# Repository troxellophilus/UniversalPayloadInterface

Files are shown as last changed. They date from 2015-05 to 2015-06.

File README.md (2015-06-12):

# UniversalPayloadInterface
Universal UAV Payload Interface Senior Project

Open Source Code & Hardware

Cal Poly SLO

* Nolan Reker
* Drew Troxell
* David Troy

More documentation coming soon!

### Getting Started

#### Requirements
* UAV utilizing the Mavlink protocol
* Onboard proxy device for running MAVProxy
* Atmega328p on payload interface board (see pcb directory for hardware details)

#### Loading the source
* Compile and upload the payload_atmega328p ino project to the atmega328p payload interface board using your favorite AVR compiler/loader.
* Connect the interface board to the onboard device via UART.
* Run MAVProxy on the onboard device w/ the master device set to the autopilot and the output device set to the UART connection to the interface board.
* The onboard LED will light up after successfully receiving 10 heartbeat packets from the autopilot.

#### Modifying the source
This code is meant to provide a simple example and framework for communicating between a payload and an autopilot via Mavlink. Reference the mavlink library for functions to decode or send more messages via mavlink.

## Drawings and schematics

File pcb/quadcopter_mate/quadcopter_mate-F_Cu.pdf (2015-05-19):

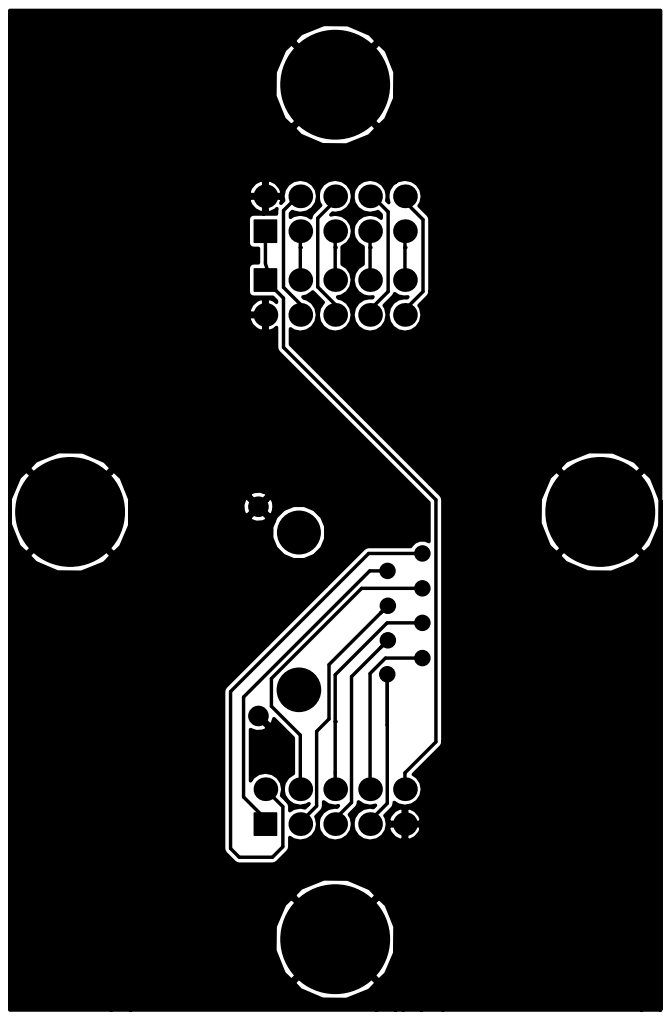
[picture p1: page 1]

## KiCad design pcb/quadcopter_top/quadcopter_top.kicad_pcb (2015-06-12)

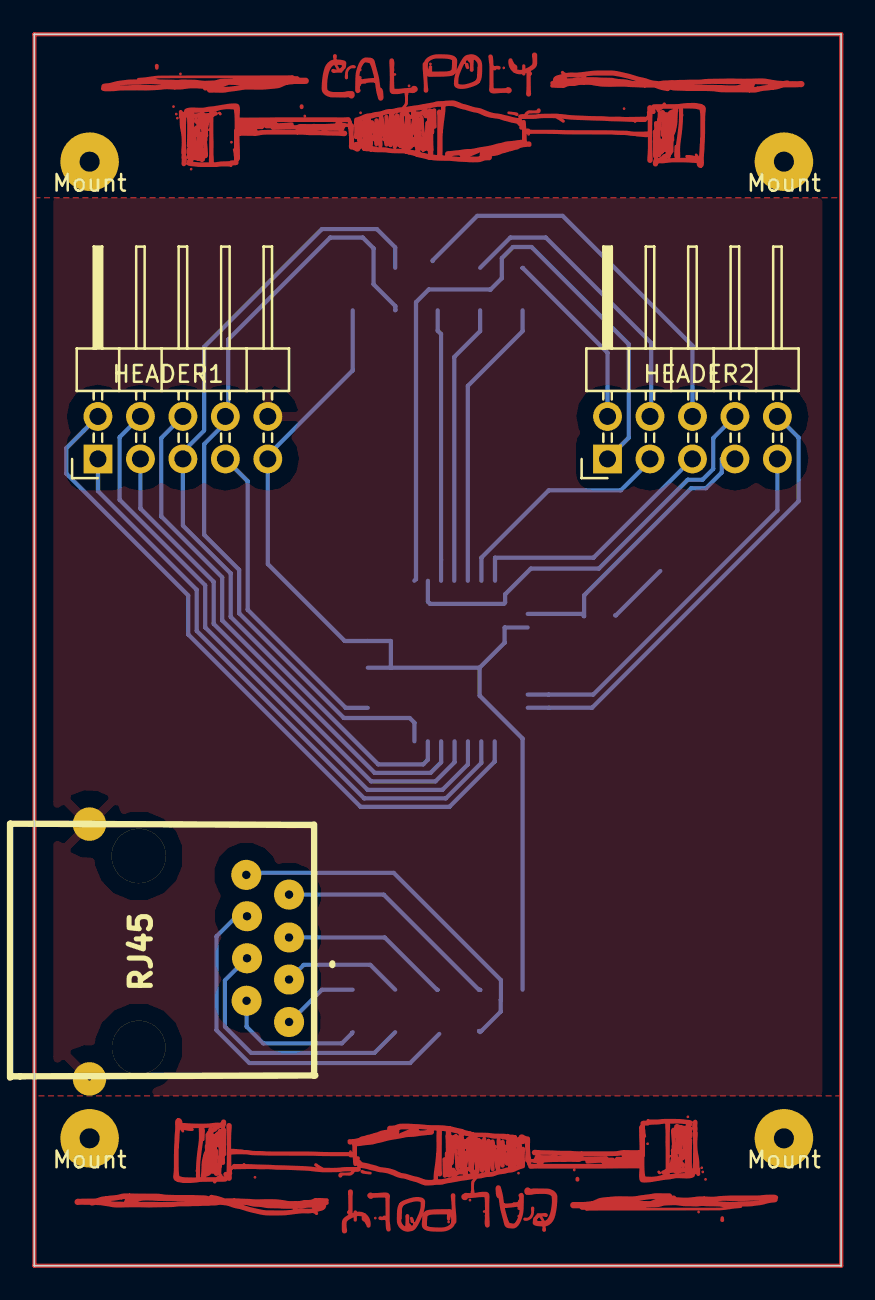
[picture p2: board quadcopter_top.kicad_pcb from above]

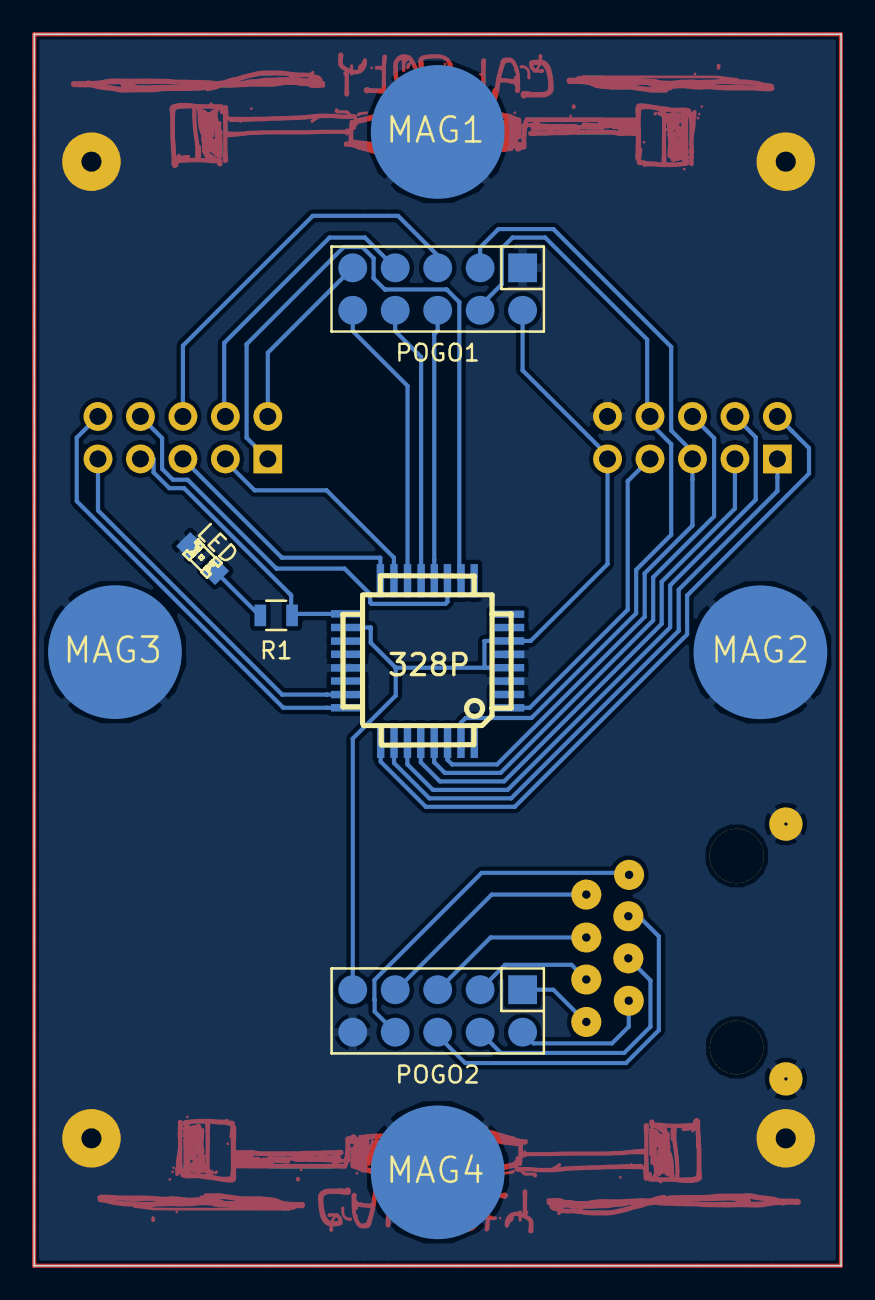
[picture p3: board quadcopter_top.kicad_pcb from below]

Board: 2 copper layers, 48.3 x 73.7 mm, 16 parts (9 on the bottom side), 32 nets.

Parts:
328P: ATMEGA328P-A; TQFP32_08
HEADER1, HEADER2: CONN_02X05; Pin_Header_Angled_2x05
J1: RJ45
LED: LED; LED-0805
MAG1, MAG2, MAG3, MAG4: CONN_01X01; 8mmMagnet
Mount: Mount; SolderWirePad_single_1-2mmDrill
Mount#2, Mount#3, Mount#4: Mount; SolderWirePad_single_1-2mmDrill
POGO1, POGO2: CONN_02X05; Pin_Header_Straight_2x05_SMD
R1: R; R_0805

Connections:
+5V: 328P.4, 328P.6, 328P.18, HEADER1.9, POGO1.2, POGO2.9
GND: 328P.3, 328P.5, 328P.21, HEADER1.10, J1.9, LED.1, MAG1.1, MAG2.1, MAG3.1, MAG4.1, POGO1.1, POGO2.10
unnamed: LED.2, R1.2
unnamed: 328P.26, HEADER1.1
unnamed: 328P.25, HEADER1.2
unnamed: 328P.28, HEADER1.3
unnamed: 328P.27, HEADER1.4
unnamed: 328P.30, HEADER1.5, POGO1.3
unnamed: 328P.29, HEADER1.6
unnamed: 328P.1, HEADER1.7
unnamed: 328P.31, HEADER1.8, POGO1.4
unnamed: 328P.10, HEADER2.1
unnamed: HEADER2.2, POGO1.9
unnamed: 328P.15, HEADER2.3
unnamed: HEADER2.4, POGO1.7
unnamed: 328P.16, HEADER2.5
unnamed: HEADER2.6, POGO1.5
unnamed: 328P.17, HEADER2.7, R1.1
unnamed: 328P.11, HEADER2.8
unnamed: 328P.23, HEADER2.9
unnamed: 328P.24, HEADER2.10
unnamed: 328P.12, POGO1.6
unnamed: 328P.13, POGO1.8
unnamed: 328P.14, POGO1.10
unnamed: J1.1, POGO2.8
unnamed: J1.2, POGO2.7
unnamed: J1.3, POGO2.6
unnamed: J1.4, POGO2.5
unnamed: J1.5, POGO2.4
unnamed: J1.6, POGO2.3
unnamed: J1.7, POGO2.2
unnamed: J1.8, POGO2.1

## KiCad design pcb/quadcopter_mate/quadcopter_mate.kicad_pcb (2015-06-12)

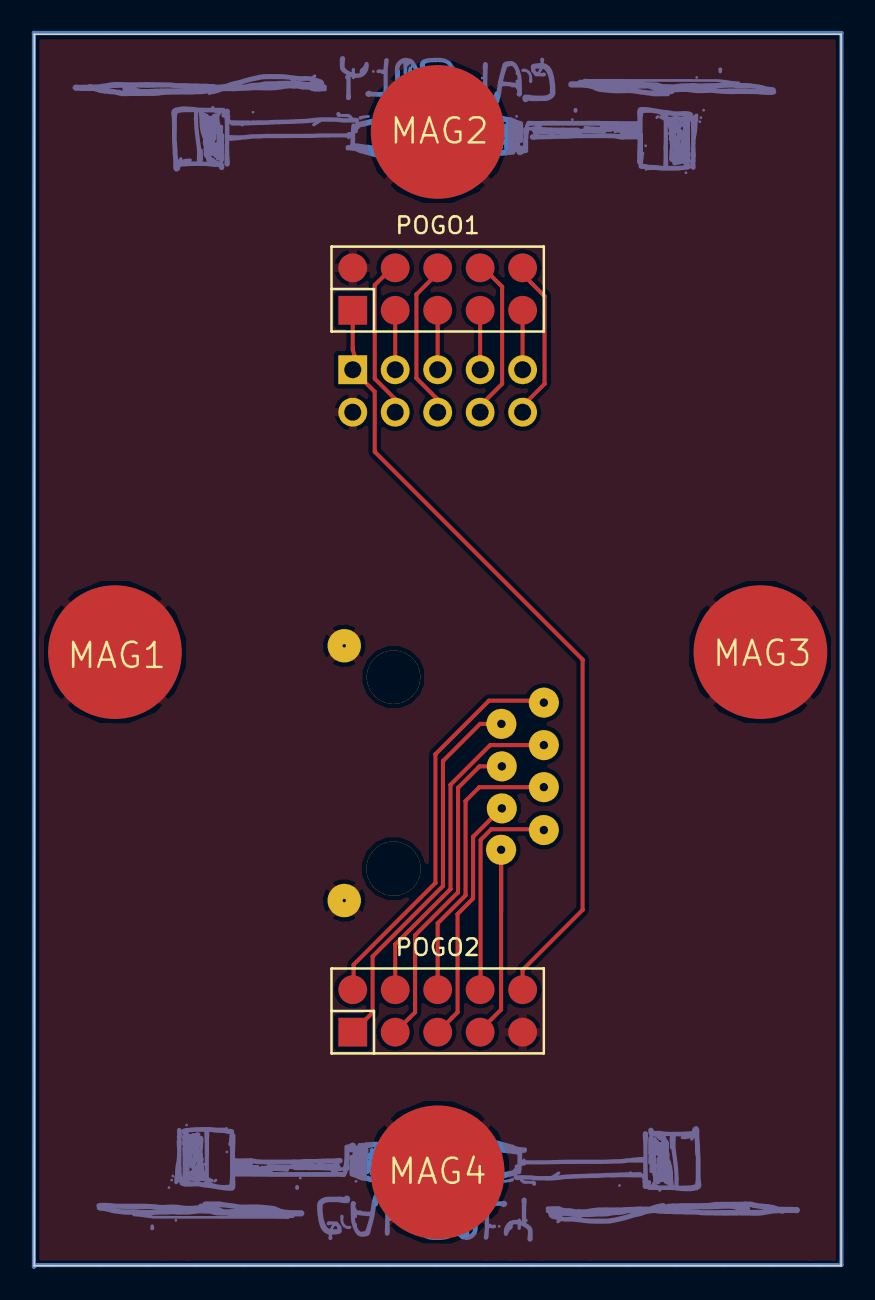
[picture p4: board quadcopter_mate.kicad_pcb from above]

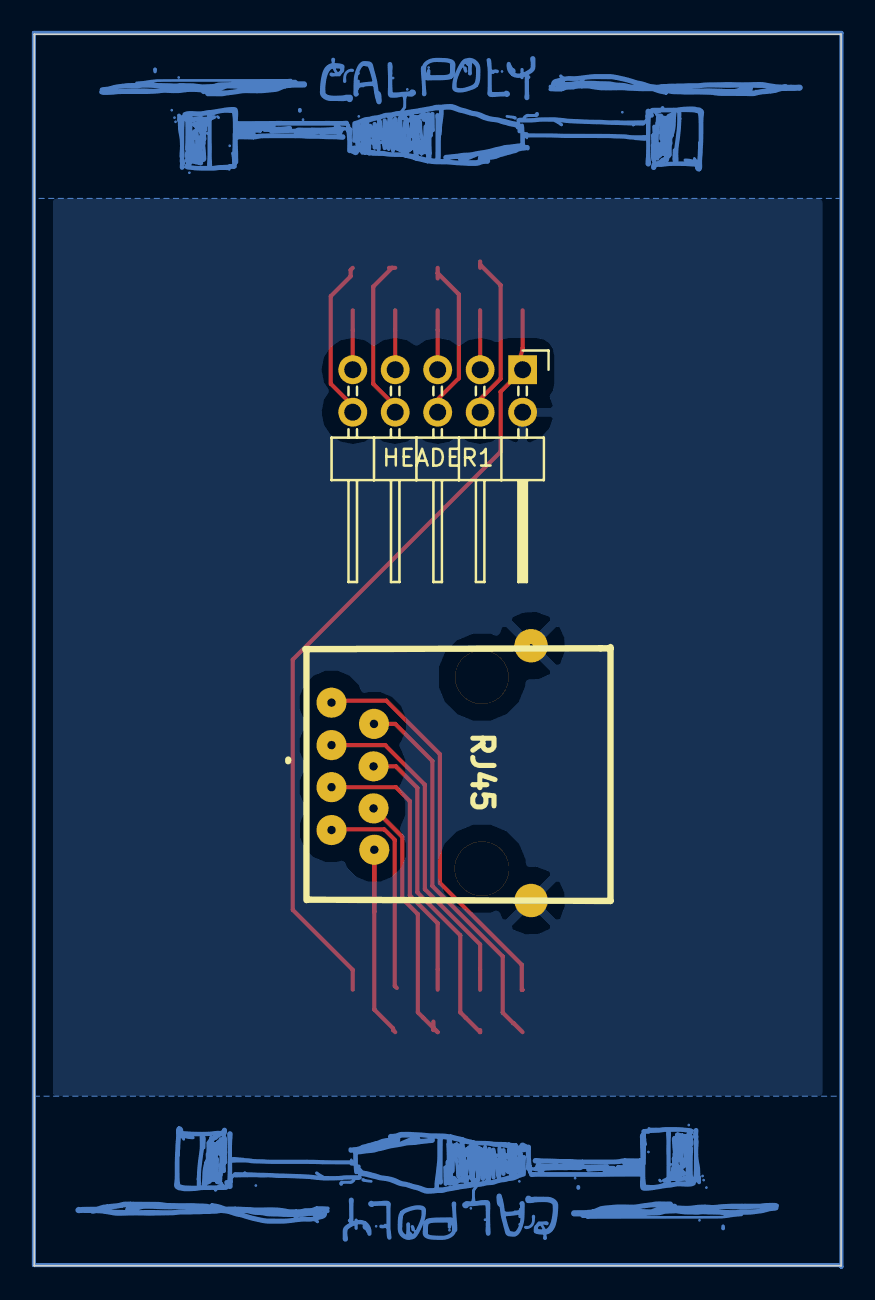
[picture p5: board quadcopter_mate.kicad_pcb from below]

Board: 2 copper layers, 48.3 x 73.7 mm, 8 parts (2 on the bottom side), 18 nets.

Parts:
HEADER1: CONN_02X05; Pin_Header_Angled_2x05
J1: RJ45
MAG1, MAG2, MAG3, MAG4: CONN_01X01; 8mmMagnet
POGO1, POGO2: CONN_02X05; Pin_Header_Straight_2x05_SMD

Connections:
+5V: HEADER1.1, POGO1.1, POGO2.10
GND: HEADER1.2, J1.9, MAG1.1, MAG2.1, MAG3.1, MAG4.1, POGO1.2, POGO2.9
unnamed: HEADER1.3, POGO1.3
unnamed: HEADER1.4, POGO1.4
unnamed: HEADER1.5, POGO1.5
unnamed: HEADER1.6, POGO1.6
unnamed: HEADER1.7, POGO1.7
unnamed: HEADER1.8, POGO1.8
unnamed: HEADER1.9, POGO1.9
unnamed: HEADER1.10, POGO1.10
unnamed: J1.1, POGO2.7
unnamed: J1.2, POGO2.8
unnamed: J1.3, POGO2.5
unnamed: J1.4, POGO2.6
unnamed: J1.5, POGO2.3
unnamed: J1.6, POGO2.4
unnamed: J1.7, POGO2.1
unnamed: J1.8, POGO2.2

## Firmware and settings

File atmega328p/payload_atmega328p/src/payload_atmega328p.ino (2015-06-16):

/*
 * Universal Payload Interface
 * Atmega328p MAVLink Code
 */

/* Make sure this is included before Arduino's HardwareSerial */
#include <FastSerial.h>

/* Make sure this is defined before including mavlink.h */
#define MAVLINK_COMM_NUM_BUFFERS 1
#include <mavlink.h>

#define PL_SYS_ID  101 // system id of the payload interface
#define PL_COMP_ID 101 // Component id of payload interface

#define NUM_WP 5 // the number of waypoints we will send to the mav

#define PL_STATE_DISCONNECTED       0
#define PL_STATE_CONNECTED          1
#define PL_STATE_SEND_WAYPOINTS     2
#define PL_STATE_FLASH_LED          3

FastSerialPort0(Serial); // Required for FastSerial

// System Status Variables
uint8_t  mavlink_connected = 0;
uint8_t  pl_state = PL_STATE_DISCONNECTED;
uint16_t hb_count = 0;
uint32_t led_pin = 13;

// Payload identifiers
uint8_t  pl_system_id = PL_SYS_ID;
uint8_t  pl_component_id = PL_COMP_ID;

// APM identifiers
uint8_t  mav_system_id = 0;
uint8_t  mav_component_id = 0;

// Waypoint Variables
uint8_t  wp_timeout = 0;
uint8_t  wp_clear_sent = 0;
uint8_t  wp_count_sent = 0;
uint8_t  wp_request_seq = 0;
mavlink_mission_item_t pl_waypoints[NUM_WP];

// *************************
// MAVLINK MESSAGE VARIABLES

// Heartbeat (msg id 1)
uint8_t  mav_type = 0;
uint8_t  mav_autopilot = 0;
uint8_t  mav_base_mode = 0;
uint8_t  mav_system_status = 0;

// Mission Current (msg id 42)
uint16_t mav_seq = 0;

// *************************
// MESSAGE SEND HELPERS

void send_message(mavlink_message_t* msg) {
	uint8_t buf[MAVLINK_MAX_PACKET_LEN];

	uint16_t len = mavlink_msg_to_send_buffer(buf, msg);

	for(uint16_t i = 0; i < len; i++) {
		Serial.write(buf[i]);
	}
}

void send_heartbeat() {
	// Define the system type (see mavlink_types.h for list of possible types) 
	int system_type = MAV_TYPE_GCS;
	int autopilot_type = MAV_AUTOPILOT_INVALID;
	int base_mode = MAV_MODE_STABILIZE_ARMED;
	int sys_status = MAV_STATE_ACTIVE;
	
	// Initialize the required buffers 
	mavlink_message_t msg; 
	
	// Setup the heartbeat message
	mavlink_msg_heartbeat_pack(pl_system_id, pl_component_id, &msg, system_type, autopilot_type, base_mode, 0, sys_status);

	send_message(&msg);
}

void send_set_waypoint(uint16_t wp) {
	mavlink_message_t msg;
	mavlink_mission_set_current_t set_point;

	set_point.seq = wp;
	set_point.target_system = mav_system_id;
	set_point.target_component = mav_component_id;

	mavlink_msg_mission_set_current_encode(pl_system_id, pl_component_id, &msg, &set_point);

	send_message(&msg);
}

void send_waypoint_count(uint16_t c) {
	mavlink_message_t msg;
	mavlink_mission_count_t wp_count;

	wp_count.count = c;
	wp_count.target_system = mav_system_id;
	wp_count.target_component = mav_component_id;

	mavlink_msg_mission_count_encode(pl_system_id, pl_component_id, &msg, &wp_count);

	send_message(&msg);
}

void send_waypoint(float lat, float lon, float alt, uint16_t seq, uint16_t com, uint8_t cur) {
	mavlink_message_t msg;
	mavlink_mission_item_t waypoint;

	waypoint.param1 = 0;
	waypoint.param2 = 0;
	waypoint.param3 = 0;
	waypoint.param4 = 0;
	waypoint.x = lat;
	waypoint.y = lon;
	waypoint.z = alt;
	waypoint.seq = seq;
	waypoint.command = com;
	waypoint.target_system = mav_system_id;
	waypoint.target_component = mav_component_id;
	waypoint.frame = MAV_FRAME_BODY_NED;
	waypoint.current = cur;
	waypoint.autocontinue = 1;

	mavlink_msg_mission_item_encode(pl_system_id, pl_component_id, &msg, &waypoint);

	send_message(&msg);
}

void send_waypoint(mavlink_mission_item_t *wp) {
	mavlink_message_t msg;

	mavlink_msg_mission_item_encode(pl_system_id, pl_component_id, &msg, wp);

	send_message(&msg);
}

void send_clear_waypoints() {
	mavlink_message_t msg;
	mavlink_mission_clear_all_t wp_clear;

	wp_clear.target_system = mav_system_id;
	wp_clear.target_component = mav_component_id;

	mavlink_msg_mission_clear_all_encode(pl_system_id, pl_component_id, &msg, &wp_clear);

	send_message(&msg);
}

void send_status_text(char * txt, MAV_SEVERITY severity) {
	mavlink_message_t msg;
	mavlink_statustext_t status_text;

	status_text.severity = severity;
	memcpy(status_text.text, txt, 50);

	mavlink_msg_statustext_encode(mav_system_id, mav_component_id, &msg, &status_text);

	send_message(&msg);
}

// ************************
// PAYLOAD UPDATE FUNCTIONS

void pl_update() {
	static uint16_t frames = 0;

	// Run payload state machine
	switch (pl_state) {
		case PL_STATE_DISCONNECTED:
			digitalWrite(led_pin, LOW);

			// Received 10 heartbeats, connection confirmed
			if (hb_count >= 10) {
				pl_state = PL_STATE_CONNECTED;

				// update the target ids in the waypoint list
				int i;
				for (i = 0; i < NUM_WP; i++) {
					pl_waypoints[i].target_system = mav_system_id;
					pl_waypoints[i].target_component = mav_component_id;
				}
			}

			// send heartbeats from the payload
			delay(10);
			send_heartbeat();

			// while a connection hasn't been established, do nothing
			break;
		case PL_STATE_CONNECTED:
			digitalWrite(led_pin, HIGH);

			if (wp_count_sent == 0) {
				// allow the autopilot to warm up
				delay(5000);

				// clear out any waypoints already on the autopilot
				//send_clear_waypoints();
				//wp_clear_sent = 1;

				pl_state = PL_STATE_SEND_WAYPOINTS;
			}

			// send heartbeats from the payload
			delay(10);
			send_heartbeat();

			break;
		case PL_STATE_FLASH_LED:
			int i;

			// flash the LED 5 times in 1 second to visually acknowledge something
			for (i = 0; i < 5; i++) {
				if (digitalRead(led_pin) == HIGH)
					digitalWrite(led_pin, LOW);
				else
					digitalWrite(led_pin, HIGH);
				delay(200);
			}

			pl_state = PL_STATE_CONNECTED;
			break;
		case PL_STATE_SEND_WAYPOINTS:
			static unsigned long last_time = millis();

			if (wp_count_sent && millis() - last_time >= 2000) {
				last_time = millis();
				wp_timeout++;

				// handle timeouts depending on current request seq
				if (wp_timeout >= 5) {
					wp_count_sent = 0;
					wp_timeout = 0;
				}
				else {
					send_waypoint(&pl_waypoints[wp_request_seq]);
				}
			}
			
			if (wp_count_sent == 0) {
				send_waypoint_count(NUM_WP);
				wp_count_sent++;
			}

			// recv handlers will handle sending waypoints when requested
			break;
	}

	frames++;
}

// ************************
// MAIN SETUP AND LOOP

void init_waypoint(float lat, float lon, float alt, uint16_t seq, uint16_t com, uint8_t cur,
							mavlink_mission_item_t *waypoint) {
	waypoint->param1 = 0;
	waypoint->param2 = 0;
	waypoint->param3 = 0;
	waypoint->param4 = 0;
	waypoint->x = lat;
	waypoint->y = lon;
	waypoint->z = alt;
	waypoint->seq = seq;
	waypoint->command = com;
	waypoint->target_system = mav_system_id;
	waypoint->target_component = mav_component_id;
	waypoint->frame = MAV_FRAME_BODY_NED;
	waypoint->current = cur;
	waypoint->autocontinue = 1;
}

void setup() {
	pinMode(led_pin, OUTPUT);
	Serial.begin(57600);

	// Initialize the waypoint list
	//   Modify the init_waypoints in the switch statement and NUM_WP to change waypoints
	int i = 0;
	mavlink_mission_item_t waypoint;
	while (i < NUM_WP) {
		switch (i) {
			case 0:
				// "Home" waypoint, gets overridden by APM
				init_waypoint(0, 0, 0, i, MAV_CMD_NAV_WAYPOINT, 0, &waypoint);
				break;
			case 1:
				// Takeoff, only cares about altitude param
				init_waypoint(0, 0, 1.0, i, MAV_CMD_NAV_TAKEOFF, 0, &waypoint);
				break;
			case 2:
				// Spin around a bit
				init_waypoint(0, 0, 0, i, MAV_CMD_CONDITION_YAW, 0, &waypoint);
				waypoint.param1 = 180.0; // degrees to spin
				waypoint.param4 = 1.0; // around current rotation
			case 3:
				// Navigate according to body frame of reference
				init_waypoint(0.0, 0.0, 1.0, i, MAV_CMD_NAV_WAYPOINT, 0, &waypoint);
				break;
			case 4:
				// Return to launch, self explanatory
				init_waypoint(0, 0, 0, i, MAV_CMD_NAV_RETURN_TO_LAUNCH, 0, &waypoint);
				break;
		}
		pl_waypoints[i] = waypoint;
		i++;
	}
}

void loop() { 
	// Carry out payload state machine
	pl_update();
	
	// Receive messages and handle them
	comm_receive();
}

// ************************
// MESSAGE RECEIVE HELPERS

void comm_receive() {
	static unsigned long last_time = millis();
	static uint8_t timeout = 0;
	int i = 0;
	int frames = 0;
	mavlink_message_t recv_msg; 
	mavlink_status_t recv_status;

	// block for 1 second on serial read
	while (Serial.available() == 0 && pl_state != PL_STATE_DISCONNECTED) {
		if (millis() - last_time >= 1000) {
			last_time = millis();
			timeout++; // block on serial read
		}

		// we haven't heard from the autopilot in 10 seconds
		if (timeout >= 10) {
			pl_state = PL_STATE_DISCONNECTED;
			mavlink_connected = 0;
			hb_count = 0;
			wp_clear_sent = 0;
			wp_count_sent = 0;
			wp_request_seq = 0;
		}
	}
	
	// receive data over serial 
	while (Serial.available() > 0) { 
		uint8_t c = Serial.read();

		//try to get a new message 
		if(mavlink_parse_char(0, c, &recv_msg, &recv_status)) { 
			timeout = 0; // reset timeout
			frames++;
			
			// Update system and component id
			mav_system_id = recv_msg.sysid;
			mav_component_id = recv_msg.compid;

			// Handle message
 			switch(recv_msg.msgid) {
			        case MAVLINK_MSG_ID_HEARTBEAT:
					handle_heartbeat(&recv_msg);
			        	break;
				case MAVLINK_MSG_ID_MISSION_CURRENT:
					handle_mission_current(&recv_msg);
					break;
				case MAVLINK_MSG_ID_MISSION_REQUEST:
					handle_mission_request(&recv_msg);
					break;
				case MAVLINK_MSG_ID_MISSION_ACK:
					handle_mission_ack(&recv_msg);
					break;
				default:
				break;
			}
		} 
		if (i > 64 || frames > 10) {
			break;
		}
		delayMicroseconds(200);
		i++;
	}
}

void handle_heartbeat(mavlink_message_t *msg) {
	hb_count++;
	mav_type = mavlink_msg_heartbeat_get_type(msg);
	mav_autopilot = mavlink_msg_heartbeat_get_autopilot(msg);
	mav_base_mode = mavlink_msg_heartbeat_get_base_mode(msg);
	mav_system_status = mavlink_msg_heartbeat_get_system_status(msg);
}

void handle_mission_current(mavlink_message_t *msg) {
	mav_seq = mavlink_msg_mission_current_get_seq(msg);
	//pl_state = PL_STATE_FLASH_LED;
}

void handle_mission_request(mavlink_message_t *msg) {
	wp_timeout = 0;
	wp_request_seq = mavlink_msg_mission_request_get_seq(msg);
	send_waypoint(&pl_waypoints[wp_request_seq]);
}

void handle_mission_ack(mavlink_message_t *msg) {
	wp_request_seq = 0;
	pl_state = PL_STATE_FLASH_LED;
}

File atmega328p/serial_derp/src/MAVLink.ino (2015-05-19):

/*
	 Mav2DupEx Version 0.1
	 2014, by DevFor8.com, info@devfor8.com
	 
	 part of code is based on ArduCAM OSD
*/

#include "../GCS_MAVLink/include/mavlink/v1.0/mavlink_types.h"
#include "../GCS_MAVLink/include/mavlink/v1.0/ardupilotmega/mavlink.h"

#include "Vars.h"

// true when we have received at least 1 MAVLink packet
static bool mavlink_active;
static uint8_t crlf_count = 0;

static int packet_drops = 0;
static int parse_error = 0;

boolean getBit(byte Reg, byte whichBit) {
    boolean State;
    State = Reg & (1 << whichBit);
    return State;
}  

/*
void request_mavlink_rates()
{
    const int  maxStreams = 6;
    const uint8_t MAVStreams[maxStreams] = {MAV_DATA_STREAM_RAW_SENSORS,
        MAV_DATA_STREAM_EXTENDED_STATUS,
        MAV_DATA_STREAM_RC_CHANNELS,
        MAV_DATA_STREAM_POSITION,
        MAV_DATA_STREAM_EXTRA1, 
        MAV_DATA_STREAM_EXTRA2};
    const uint16_t MAVRates[maxStreams] = {0x02, 0x02, 0x05, 0x02, 0x05, 0x02};
    for (int i=0; i < maxStreams; i++) {
        mavlink_msg_request_data_stream_send(MAVLINK_COMM_0,
            apm_mav_system, apm_mav_component,
            MAVStreams[i], MAVRates[i], 1);
    }
}
*/

void read_mavlink(int maxframes){
    mavlink_message_t msg; 
    mavlink_status_t status;
    int current_frames = 0;

    //grabing data 
    while(Serial.available() > 0) { 
        uint8_t c = Serial.read();
        //Serial.print(c);        Serial.print(" ");

        //trying to grab msg  
        if(mavlink_parse_char(MAVLINK_COMM_0, c, &msg, &status)) {
            mavlink_active = 1;
            current_frames++; //this is frame
            //handle msg
            switch(msg.msgid) {
            case MAVLINK_MSG_ID_HEARTBEAT:
                {
                  Serial.println("beat");
                    mavbeat = 1;
                    apm_mav_system    = msg.sysid;
                    apm_mav_component = msg.compid;
                    apm_mav_type      = mavlink_msg_heartbeat_get_type(&msg);            
                 //   osd_mode = mavlink_msg_heartbeat_get_custom_mode(&msg);
                    osd_mode = (uint8_t)mavlink_msg_heartbeat_get_custom_mode(&msg);
                    //Mode (arducoper armed/disarmed)
                    base_mode = mavlink_msg_heartbeat_get_base_mode(&msg);
                    if(getBit(base_mode,7)) motor_armed = 1;
                    else motor_armed = 0;

                    lastMAVBeat = millis();
                    if(waitingMAVBeats == 1){
                        enable_mav_request = 1;
                    }
                }
                break;
            case MAVLINK_MSG_ID_STATUSTEXT:
                {
                  Serial.println("stext");
                  char text[MAVLINK_MSG_ID_STATUSTEXT_LEN] ;
                  mavlink_msg_statustext_get_text(&msg,&text[0]);
                  strncpy((char*)LastMessage,text,LCDMaxPos);
                  break;
                }
            case MAVLINK_MSG_ID_SYS_STATUS:
                {
                  Serial.println("status");
                    osd_vbat_A = (mavlink_msg_sys_status_get_voltage_battery(&msg) / 1000.0f); //Battery voltage, in millivolts (1 = 1 millivolt)
                    osd_curr_A = (mavlink_msg_sys_status_get_current_battery(&msg) / 100.0f); //Battery current, in 10*milliamperes (1 = 10 milliampere)         10
                    osd_battery_remaining_A = mavlink_msg_sys_status_get_battery_remaining(&msg); //Remaining battery energy: (0%: 0, 100%: 100)
                }
                break;

            case MAVLINK_MSG_ID_GPS_RAW_INT:
                {
                  Serial.println("gps:");
                    osd_lat = mavlink_msg_gps_raw_int_get_lat(&msg) / 10000000.0f;
                    osd_lon = mavlink_msg_gps_raw_int_get_lon(&msg) / 10000000.0f;
                    osd_fix_type = mavlink_msg_gps_raw_int_get_fix_type(&msg);
                    osd_satellites_visible = mavlink_msg_gps_raw_int_get_satellites_visible(&msg);
                  //serial.println(osd_fix_type);

                }
                break; 
            case MAVLINK_MSG_ID_VFR_HUD:
                {
                  Serial.println("hud:");
                    //osd_airspeed = mavlink_msg_vfr_hud_get_airspeed(&msg);
                    //osd_groundspeed = mavlink_msg_vfr_hud_get_groundspeed(&msg);
                    osd_heading = mavlink_msg_vfr_hud_get_heading(&msg); // 0..360 deg, 0=north
                  //Serial.println(osd_heading);  
                    //osd_throttle = mavlink_msg_vfr_hud_get_throttle(&msg);
                    //if(osd_throttle > 100 && osd_throttle < 150) osd_throttle = 100;//Temporary fix for ArduPlane 2.28
                    //if(osd_throttle < 0 || osd_throttle > 150) osd_throttle = 0;//Temporary fix for ArduPlane 2.28
                    osd_baro_alt = mavlink_msg_vfr_hud_get_alt(&msg);
                    //osd_climb = mavlink_msg_vfr_hud_get_climb(&msg);
                }
                break;
            case MAVLINK_MSG_ID_ATTITUDE:
                {
                  Serial.println("atti");
                    //osd_pitch = ToDeg(mavlink_msg_attitude_get_pitch(&msg));
                    //osd_roll = ToDeg(mavlink_msg_attitude_get_roll(&msg));
                    //osd_yaw = ToDeg(mavlink_msg_attitude_get_yaw(&msg));
                  //Serial.print(osd_pitch);  Serial.print("  / ");Serial.print(osd_roll);  Serial.print("  / ");Serial.println(osd_yaw); 
                }
                break;

            default:
                {
                    
                    Serial.print("unk:");Serial.println(msg.msgid);
                }
                break;
            }
        delayMicroseconds(200); //wait just between frames, not eaach character
      }
        
        //next one
        if (current_frames>maxframes)
          break; //we need time for Jeti
    }
    // Update global packet drops counter
    packet_drops += status.packet_rx_drop_count;
    parse_error += status.parse_error;

}

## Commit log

2015-05-18 Current state, no correct reception from apm yet.
    [payload_atmega328p.ino]
2015-05-18 Consistently gets initial heartbeat after a reset
    [MAVLink.ino, Vars.h, mavtest.ino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]
2015-05-19 added PCB designs
    KiCad PCB designs. The one labeled top is actually bottom. May fix that at some point. Please make sure all references in KiCad files remain relative to the project dir to avoid broken dependencies.
    [quadcopter_mate.dsn, quadcopter_mate.kicad_pcb, quadcopter_mate.sch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]
2015-05-19 Added cal poly logo and set up backside
    [quadcopter_mate.dsn, quadcopter_mate.kicad_pcb, quadcopter_top.dsn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]
2015-05-19 changed default outputs directory to share folder between both PCB's
    [quadcopter_mate.kicad_pcb, quadcopter_top.kicad_pcb]
2015-05-27 Mirrored text in mate board to be correct when gerber is mirrored
    [quadcopter_mate.kicad_pcb]
2015-05-29 fixed silkscreen, added mounting holes, added 3D models
    [quadcopter_mate.kicad_pcb, quadcopter_top.kicad_pcb]
2015-06-12 Reformatted schematics
    [quadcopter_mate.kicad_pcb, quadcopter_mate.sch, quadcopter_top.kicad_pcb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]
2015-06-15 Current state, wps still not loading right (but closer).
2015-06-15 Added IDs for payload system and component. Fixed send state resend conditions.
    [payload_atmega328p.ino]
2015-06-15 Fixed timeout on wp send
    [payload_atmega328p.ino]
